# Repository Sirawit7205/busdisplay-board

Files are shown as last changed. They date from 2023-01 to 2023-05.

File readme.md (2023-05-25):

# Busdisplay

This is an open-source KiCad design files for a circuit that could be connected to an 8-bit bus to monitor the value on it in decimal or hexadecimal.

## The board

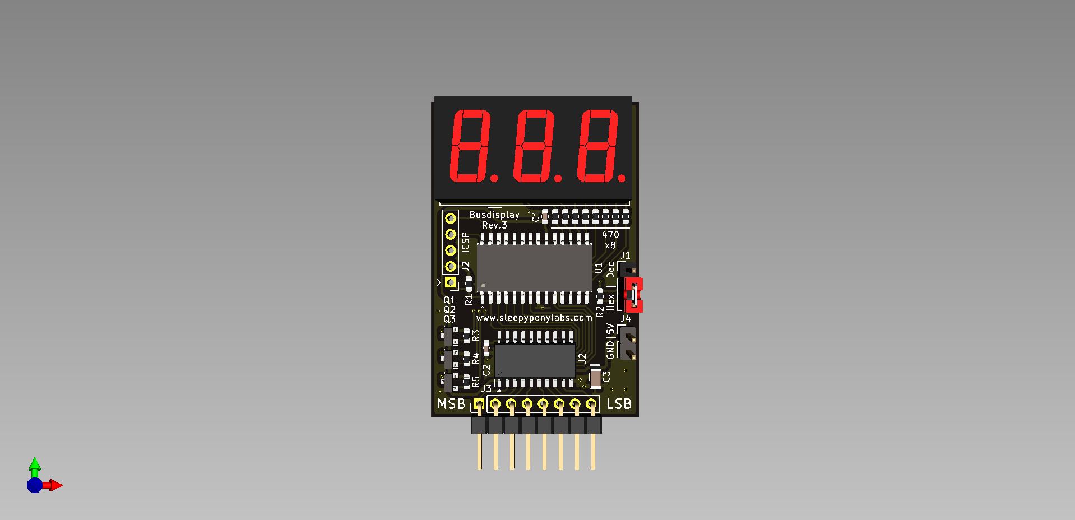
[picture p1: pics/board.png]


The board is 33x50mm (perfect for 3x2 panel). Featuring:

- PIC16F570 Microcontroller + ICSP header
- 74HCT245 Transceiver as an input buffer
- 3-digit 7-segment Display
- Hex/Dec Selector Header
- Power and Data Input Headers

We are currently at Revision 3. Changelog is below:

**Revision 3 (June 2021)**

 - Replaced PIC16F57 with PIC16F570, cheaper and more powerful.
 - Removed an external crystal because new PIC now has internal oscillator.
 - Removed buffer chip disable header, nothing shares ICSP pins now.
 - Added a bulk capacitor.
 - Redone the PCB again because new PIC has very different pinout.

**Revision 2 (May 2021)**
 - Added a header to disable the buffer chip, which would then allow the ICSP header to work.
 - Added a pull-up resistor for Selector Header.
 - Replaced HC-49 4MHz crystal with 5032 8Mhz crystal.
 - Replaced an 74HCT244 with 74HCT245 for easier routing.
 - Redone the PCB so every parts are on the top layer, and that the mosfets are not under the display.
 
**Revision 1 (January 2020)**
- Initial Design on [EasyEDA](https://easyeda.com/lsirawit24/8-bit-display)
- This version has several mistakes, for example, the ICSP header does not work, and the pull-up/down resistor is missing on Selector Header.

## What is provided

The goal of this repository is to enable you to build this on your own as easy as possible (although I originally plan to sell this as a kit as well). **I've included all of the schematics, gerbers, BOMs, and display driver firmware for you to use.** 

Hardware is licensed under `SPDX-License-Identifier: CERN-OHL-S-2.0`

Software is licensed under `SPDX-License-Identifier: GPL`

Documentation is licensed under `SPDX-License-Identifier: CC-BY-SA-4.0`

**This project is an OSHWA Certified Open Source Hardware Project with UID [TH000009](https://certification.oshwa.org/th000009.html).**

Unfortunately. I have to excluded the 3D models use to render the board in KiCAD because I don't know how each of them was licensed. They are all from GrabCad and you could search and download them by yourself.

**Note: Due to this, there might be a popup warning you about "3D model Search Path" in PCBNew. I honestly don't know how to fix this but it will not affect any KiCAD functionality.**

## Credits

 - 3-digit LED Display model by Robert Dee: https://grabcad.com/library/3-digit-led-display-1
 - Pin header and Jumpers model by singlefonts: https://grabcad.com/library/pin-header-and-jumper-1
 - SOIC package collection by Egor Chugay: https://grabcad.com/library/soic-package-collection-1/details?folder_id=5653384

> Written with [StackEdit](https://stackedit.io/).

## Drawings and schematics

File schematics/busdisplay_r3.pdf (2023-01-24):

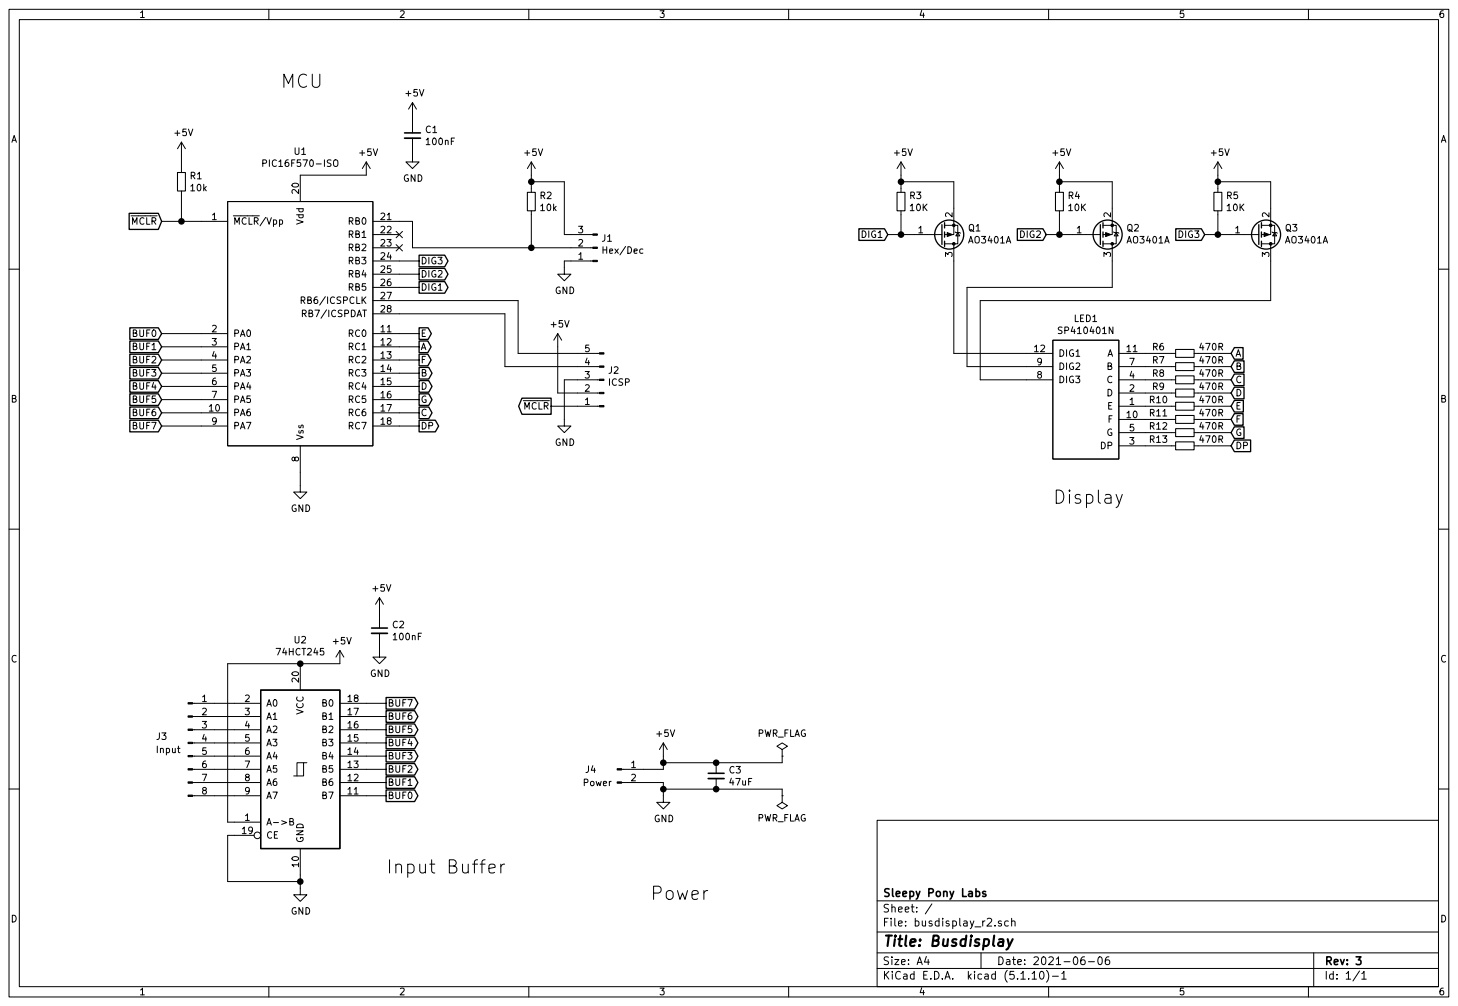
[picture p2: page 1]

File: busdisplay_r2.sch Sheet: / Sleepy Pony Labs

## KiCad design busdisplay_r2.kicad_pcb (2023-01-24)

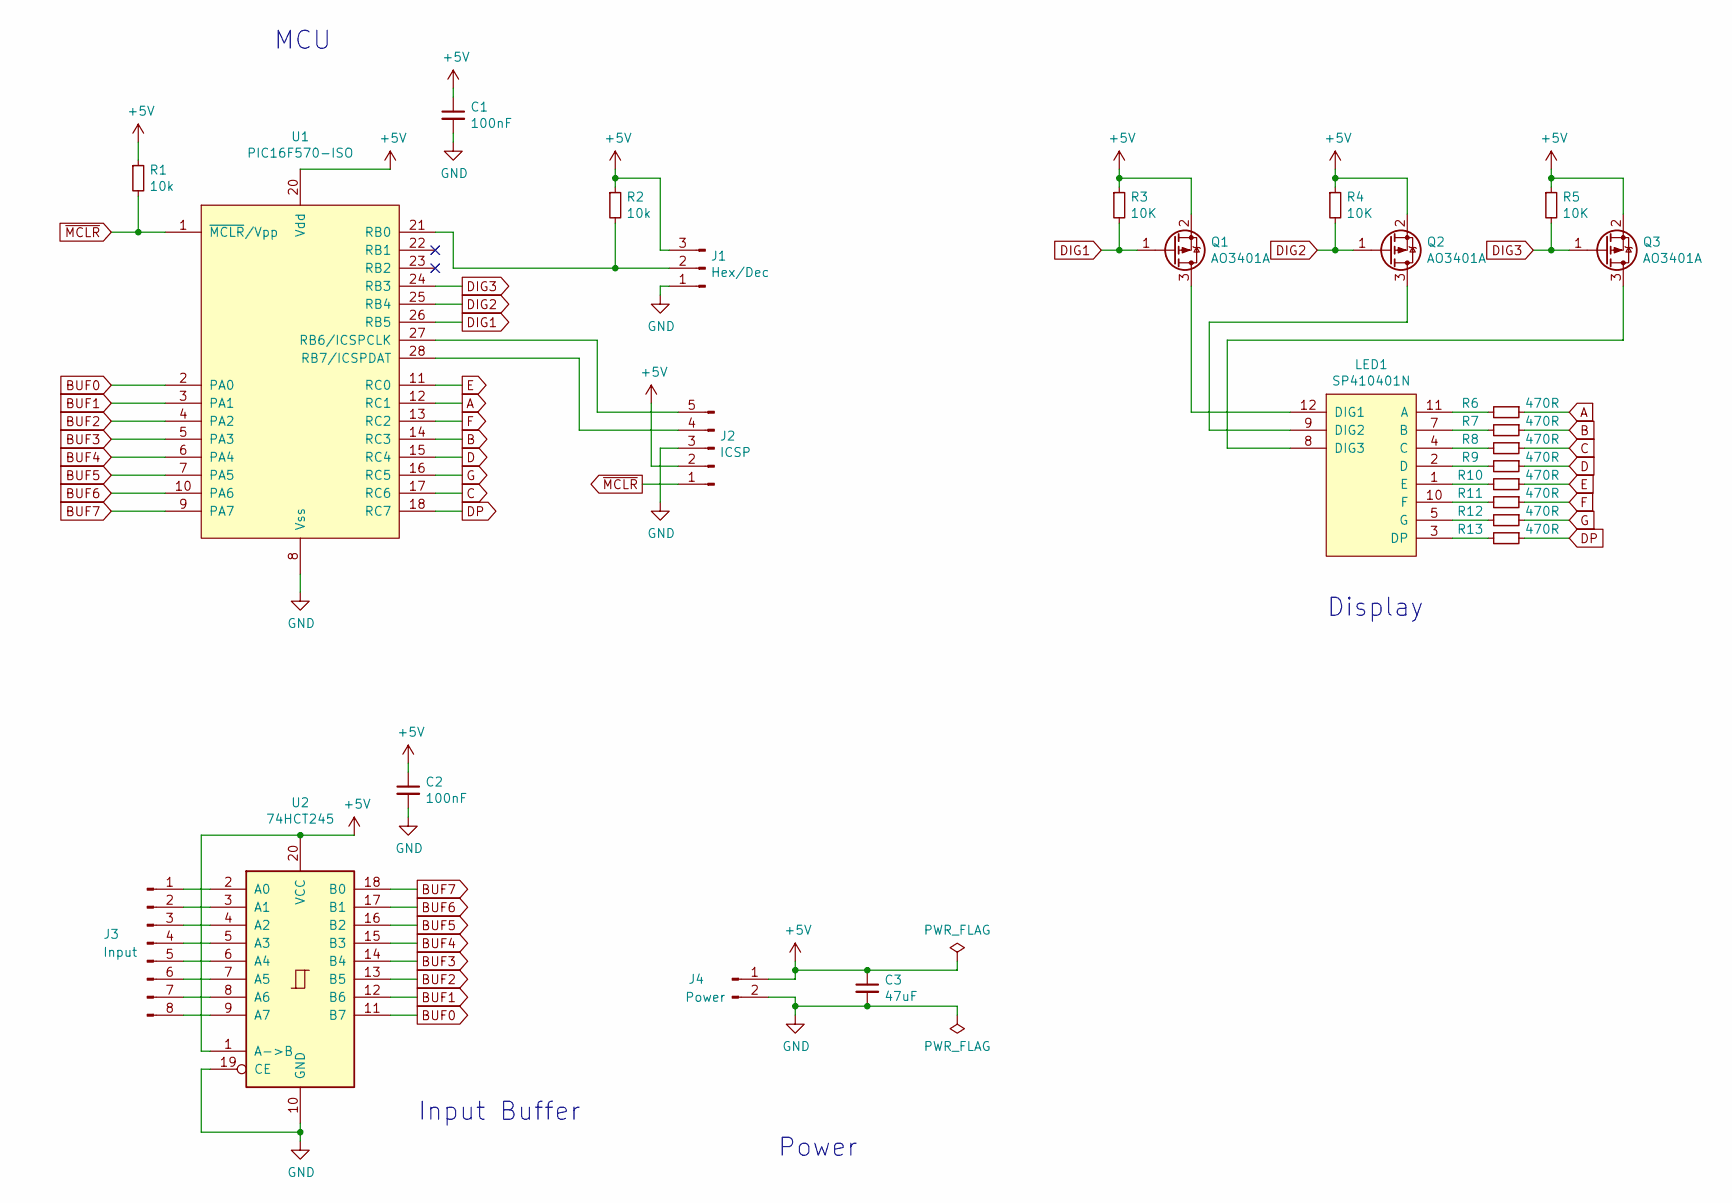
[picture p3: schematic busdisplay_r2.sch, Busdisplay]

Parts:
C1, C2: 100nF; C_0603_1608Metric
C3: 47uF; C_1206_3216Metric
J1: Hex/Dec; PinHeader_1x03_P2.54mm_Vertical
J2: ICSP; PinHeader_1x05_P2.54mm_Vertical
J3: Input; PinHeader_1x08_P2.54mm_Vertical
J4: Power; PinHeader_1x02_P2.54mm_Vertical
LED1: SP410401N
Q1, Q2, Q3: AO3401A; SOT-23
R1, R2: 10k; R_0603_1608Metric
R3, R4, R5: 10K; R_0603_1608Metric
R6, R7, R8, R9, R10, R11, R12, R13: 470R; R_0603_1608Metric
U1: PIC16F570-ISO; SOIC-28W_7.5x17.9mm_P1.27mm
U2: 74HCT245; SO-20_5.3x12.6mm_P1.27mm

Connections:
+5V: C1.1, C2.1, C3.1, J1.3, J2.2, J4.1, Q1.2 (S), Q2.2 (S), Q3.2 (S), R1.1, R2.1, R3.1, R4.1, R5.1, U1.20 (Vdd), U2.1 (A->B), U2.20 (VCC)
A: R6.1, U1.12 (RC1)
B: R7.1, U1.14 (RC3)
BUF0: U1.2 (PA0), U2.11 (B7)
BUF1: U1.3 (PA1), U2.12 (B6)
BUF2: U1.4 (PA2), U2.13 (B5)
BUF3: U1.5 (PA3), U2.14 (B4)
BUF4: U1.6 (PA4), U2.15 (B3)
BUF5: U1.7 (PA5), U2.16 (B2)
BUF6: U1.10 (PA6), U2.17 (B1)
BUF7: U1.9 (PA7), U2.18 (B0)
C: R8.1, U1.17 (RC6)
D: R9.1, U1.15 (RC4)
DIG1: Q1.1 (G), R3.2, U1.26 (RB5)
DIG2: Q2.1 (G), R4.2, U1.25 (RB4)
DIG3: Q3.1 (G), R5.2, U1.24 (RB3)
DP: R13.1, U1.18 (RC7)
E: R10.1, U1.11 (RC0)
F: R11.1, U1.13 (RC2)
G: R12.1, U1.16 (RC5)
GND: C1.2, C2.2, C3.2, J1.1, J2.3, J4.2, U1.8 (Vss), U1.19 (Vss), U2.10 (GND), U2.19 (CE)
unnamed: J1.2, R2.2, U1.21 (RB0)
unnamed: J2.4, U1.28 (RB7/ICSPDAT)
unnamed: J2.5, U1.27 (RB6/ICSPCLK)
unnamed: J3.1, U2.2 (A0)
unnamed: J3.2, U2.3 (A1)
unnamed: J3.3, U2.4 (A2)
unnamed: J3.4, U2.5 (A3)
unnamed: J3.5, U2.6 (A4)
unnamed: J3.6, U2.7 (A5)
unnamed: J3.7, U2.8 (A6)
unnamed: J3.8, U2.9 (A7)
unnamed: LED1.1 (E), R10.2
unnamed: LED1.2 (D), R9.2
unnamed: LED1.3 (DP), R13.2
unnamed: LED1.4 (C), R8.2
unnamed: LED1.5 (G), R12.2
unnamed: LED1.7 (B), R7.2
unnamed: LED1.8 (DIG3), Q3.3 (D)
unnamed: LED1.9 (DIG2), Q2.3 (D)
unnamed: LED1.10 (F), R11.2
unnamed: LED1.11 (A), R6.2
unnamed: LED1.12 (DIG1), Q1.3 (D)
~MCLR: J2.1, R1.2, U1.1 (~MCLR~/Vpp)

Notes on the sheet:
Display
MCU
Input Buffer
Power

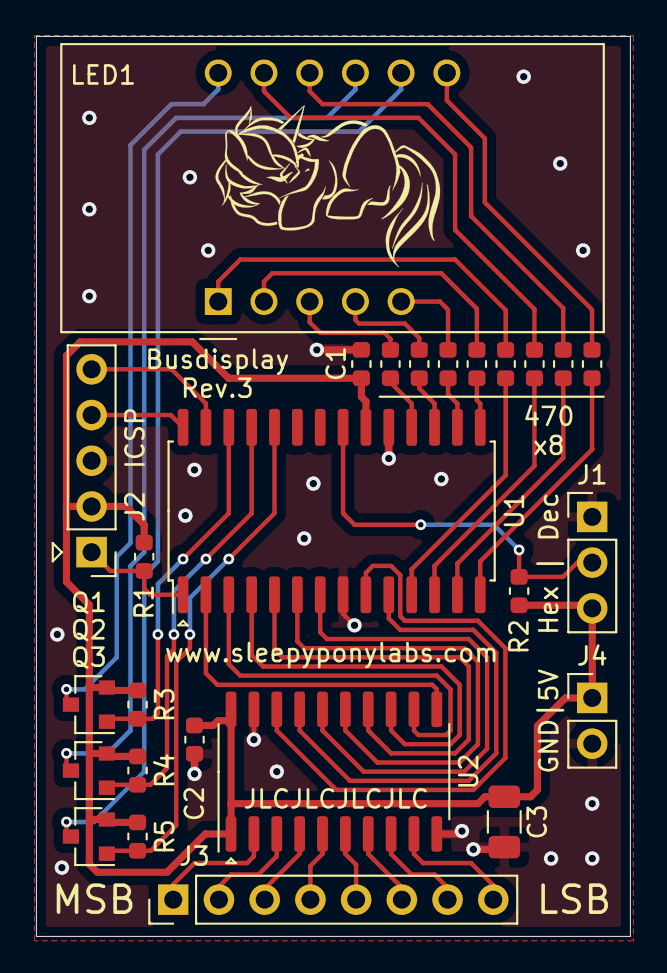
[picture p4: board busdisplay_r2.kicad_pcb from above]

Board: 2 copper layers, 33.0 x 50.0 mm, 26 parts (0 on the bottom side), 44 nets.

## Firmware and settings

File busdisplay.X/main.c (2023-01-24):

/*
 *  7-segment multiplexing
 * 
 *  RB0 = Hex(1)/Dec(0) selector input
 *  RB1 = NC
 *  RB2 = NC
 *  RB3 = Right anode
 *  RB4 = Center anode
 *  RB5 = Left anode
 *  RB6 = ICSPCLK
 *  RB7 = ICSPDAT
 *  
 *  PORTA = Data input
 *  PORTC = Cathode (DP,C,G,D,B,F,A,E)
 */

// CONFIG
#pragma config FOSC = INTRC_IO  // Oscillator (INTRC with I/O function on OSC2/CLKOUT)
#pragma config WDTE = ON        // Watchdog Timer Enable bit (Enabled)
#pragma config CP = OFF         // Code Protection bit (Code protection off)
#pragma config IOSCFS = 4MHz    // Internal Oscillator Frequency Select (4 MHz INTOSC Speed)
#pragma config CPSW = OFF       // Code Protection bit - Flash Data Memory (Code protection off)
#pragma config BOREN = ON       //  (BOR Enabled)
#pragma config DRTEN = ON       //  (DRT Enabled)

#define _XTAL_FREQ 4000000

#include <xc.h>

unsigned char digits[16] = {160,183,196,133,147,137,136,177,128,129,144,138,232,134,200,216};

int main(void) {
    
    int t;
    
    OPTION = 0xFF;  //set WDT prescaler
    
    TRISA = 0xFF;   //RA = input
    TRISB = 0xC7;   //RB0 = input, RB3,4,5 = output
    TRISC = 0x00;   //RC = output
    
    PORTB = 0x00;   //turn off all anodes
    PORTC = 0xFF;   //turn off all cathodes
    
    ANSEL = 0x00;   //disable analog inputs
    CM1CON0 &= ~_CM1CON0_C1ON_MASK;    //disable analog comp
    CM2CON0 &= ~_CM2CON0_C2ON_MASK;    //disable analog comp
    
    while(1)
    {
        asm("CLRWDT");  //clear WDT
        
        if(RB0 == 1)    //hex
        {
            t = PORTA;
            
            //disable left
            RB5 = 1;
        
            //center
            PORTC = digits[t >> 4];
            RB4 = 0;
            __delay_ms(3);
            RB4 = 1;
            //__delay_ms(10);
            
            //right
            PORTC = digits[t & 0x0F];
            RB3 = 0;
            __delay_ms(3);
            RB3 = 1;
            //__delay_ms(10);
        }    
        else            //dec
        {
            t = PORTA;
        
            //left
            PORTC = digits[t / 100];
            t = t % 100;
            RB5 = 0;
            __delay_ms(3);
            RB5 = 1;
            //__delay_ms(10);
            
            //center
            PORTC = digits[t / 10];
            t = t % 10;
            RB4 = 0;
            __delay_ms(3);
            RB4 = 1;
            //__delay_ms(10);
            
            //right
            PORTC = digits[t];
            RB3 = 0;
            __delay_ms(3);
            RB3 = 1;
            //__delay_ms(10);
        }
    }
    
    return 0;
}

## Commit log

2021-06-06 Revision 2 of the board
    [busdisplay_r2.kicad_pcb, busdisplay_r2.sch]
2021-06-06 Revision 3 files
    [busdisplay_r2-B_Cu.gbr, busdisplay_r2-B_Mask.gbr, busdisplay_r2-B_SilkS.gbr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]
2021-06-06 Add missing assets
    [busdisplay_r2-B_Cu.gbr, busdisplay_r2-B_Mask.gbr, busdisplay_r2-B_SilkS.gbr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]
2021-09-01 Add firmware, gerbers and ibom
    [busdisplay_r2-B_Cu.gbr, busdisplay_r2-B_Mask.gbr, busdisplay_r2-B_SilkS.gbr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]
